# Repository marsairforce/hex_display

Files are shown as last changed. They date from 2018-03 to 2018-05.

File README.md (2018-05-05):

A 4 digit (16 bit) binary to 7-segment display.

Wanting to have some convenient module for displaying address bus contents.

# What is this and why would I want this?
If you were playing with an old retro computer type of architecture, on a breadboard, and you wanted to view the contents of like the address bus, or a data bus as a hexadecimal value.

In a simpler time when building microcontrollers using discrete CPU to simple static RAM and EEPROM devices. Back when the interconnects between teh CPU, ROM, RAM, and peripherals were the separate parallel busses, like simple 16 bit address bus, 8 bit data bus, the control bus, etc.

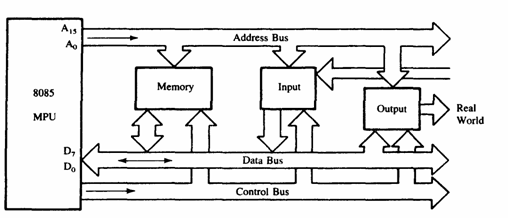
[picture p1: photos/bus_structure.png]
bus stucture


Now a days one would just spend $20 and get an Arduino, or $30 and get a Raspberry pi. and then connect it by USB to your laptop. And make use of the variety of widely avaialable community software. The hard work of design has been done for you.

But when working with these old parallel binary bus types of architectures, it is useful to be able to see what is going on when you are developing the hardware and the bare-metal software.

Usually you would be a monitor and debug panel with LED and switches on it. And then you have to look at the LEDs and interpret the value of these.

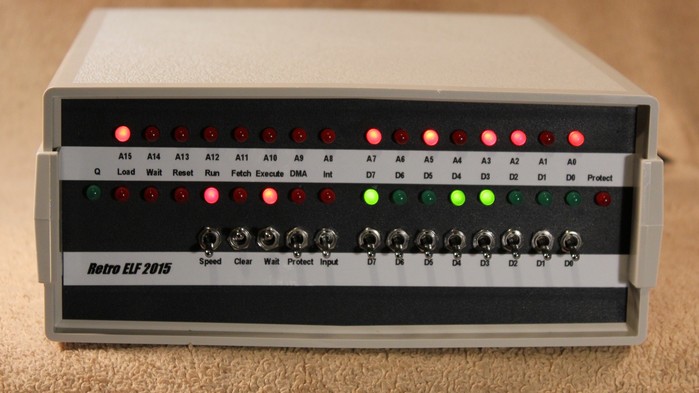
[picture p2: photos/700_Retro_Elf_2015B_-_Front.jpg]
led panel


Photo from [astrorat.com](http://www.astrorat.com/cosmacelf/retroelf2015.html)

But if you are used to thinking in base 16 instead of binary, then having a hexadecimal display is much better. Trying to fight the process and interpret the binary LEDS is very slow, tedious, and error prone.

Only usually if you have to want a binary-to-hex display, then you have wire up your own decoder, because there does not readily exist a binary-to-hex decoder IC.

Ok, so we can think about this and design a truth table for what pins to the LED display we want to have activated depending on what binary input there is.
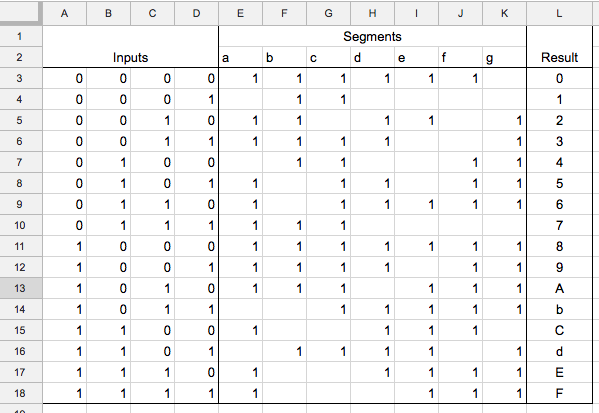
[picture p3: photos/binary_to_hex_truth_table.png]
truth table


You want to make four of these for your 16 bit address bus and another two for your 8 bit data bus. The discrete logic components required to do this take up as much if not more breadboard space as the rest of your microcontroller circuits. And the displays are horribly spaced randomly about your breadboard and you can hardly read them now too.

I guess sometimes it is possible where you might have access to a [GAL device](https://en.wikipedia.org/wiki/Generic_array_logic), but not as likely that you would have, or can afford, the programmer for these, because you are just an enthustiac hobbyist and trying to learn something new here and only have a pile of ~~rubbish~~ retro computer parts and a breadboard to play with. That would be awesome and elegant to craft a single inexpensive DIP device as your binary to Hex digit decoder though...

But then it is still tedious and error prone to have to wire up your testing tools when you are trying to use them to test things. Because every time you wire it up you have to go through the process of testing your testing tool.

What if you just had a convenient module you could just plug into a breadboard and have it readily display the decoded bus contents. That is what this does.

Inspired by https://www.youtube.com/watch?v=o9eQ9NhFT60

# V1 Hardware
This is a 28 DIP form factor circuit board using an Atmega 164A. Because it has a lot of IO pins.

Using Atmega164A device and 4 10mm 7 segment displays.

<table>
<tr><td>
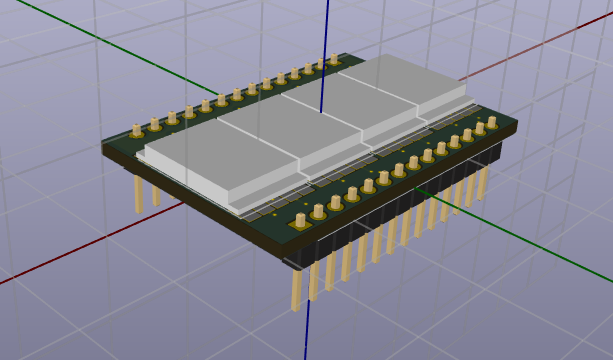
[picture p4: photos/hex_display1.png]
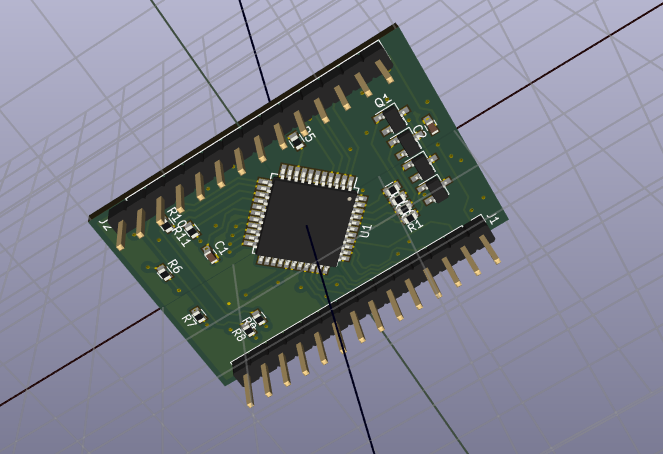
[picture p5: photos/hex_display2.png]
</td><td></td></tr></table>

The device was chosen because it has enough IO pins to directly drive all the segments with display multiplexing (the common anodes, using a transistor driver).

It was supposed to be a 28 pin dip format, but it is accidentally almost too wide to fit on a breadboard. Well, almost too wide. Some creative wiring under the display module on the breadboard should work.

Since we have pins for the MISO, MOSI, SCK. We can have a mode where this thing is an I2C or SPI slave and displays values on an I2C bus? That might be an intersting use. A display module. Though I would probably just use it as a clock since thats all I seem to build these days.

The schematic is set up to have the 16 address pins, an output enable pin and a latch enable pin.

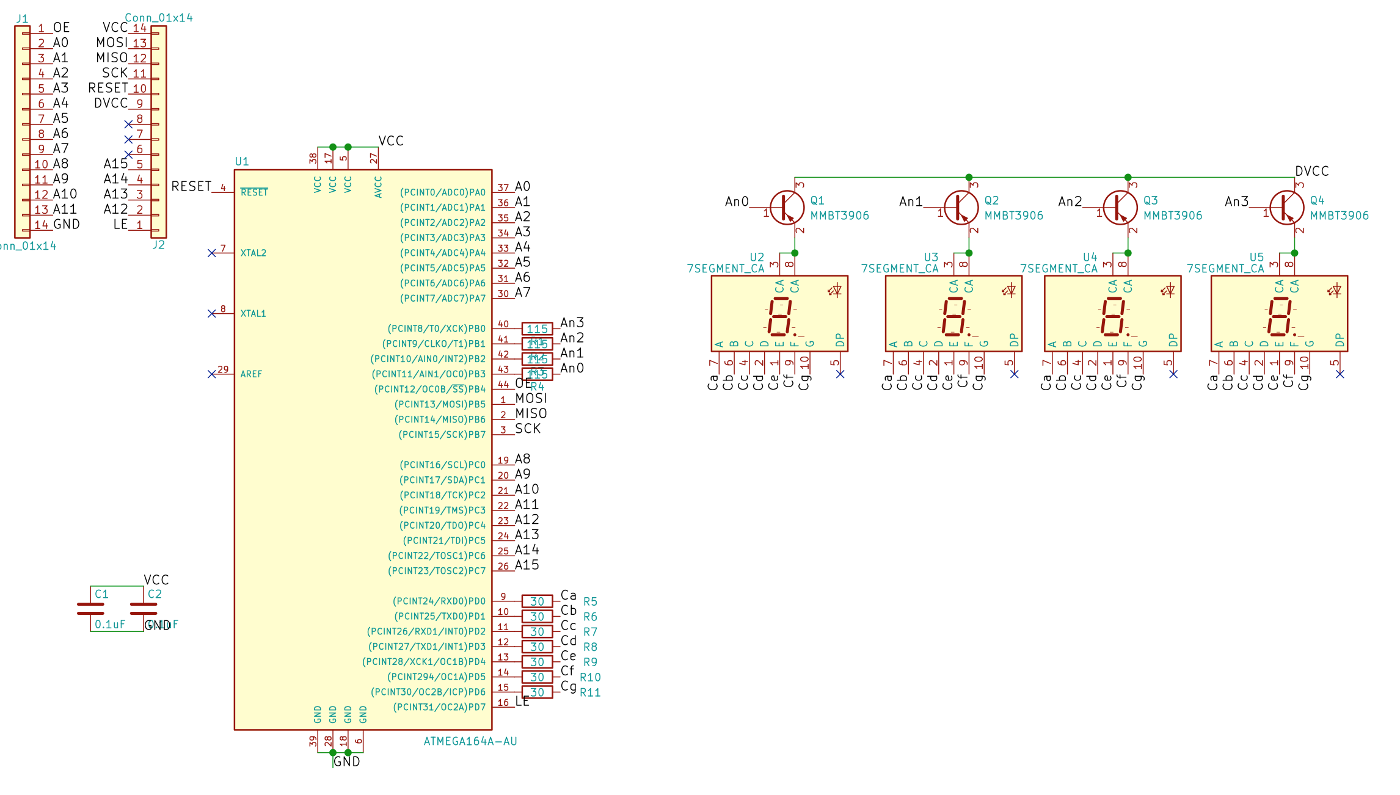
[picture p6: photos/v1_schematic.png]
v1 schematic


So the idea is to read the input pin values. and then display value as hex, using software to multiplex the displays.

And then here it is built and getting tested.
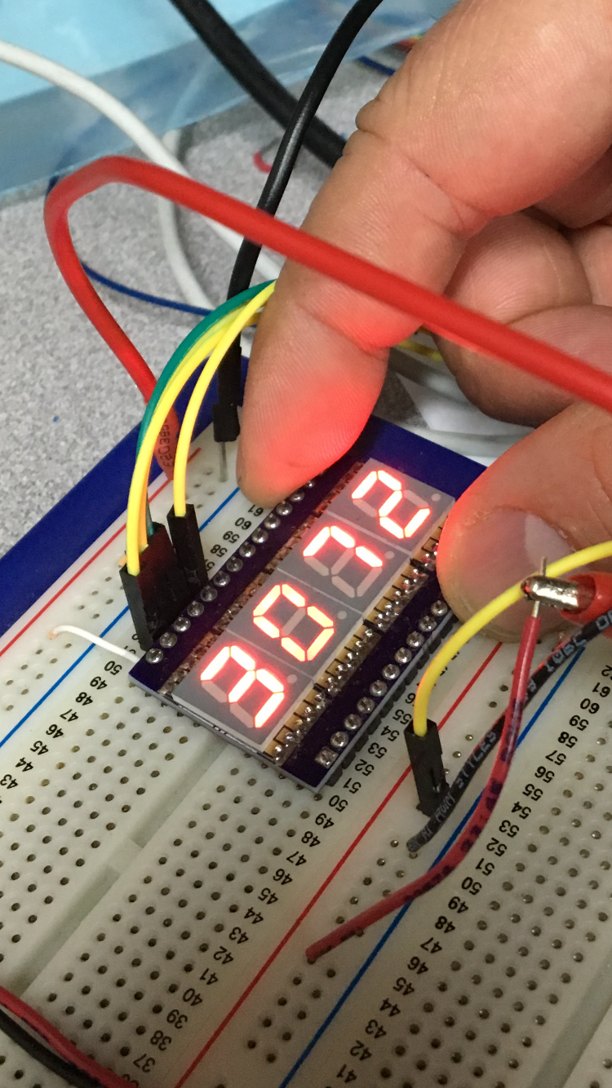
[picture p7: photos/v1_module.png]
v1 module


I made a small program to just loop and count up digits to test it, so I don't have to wire up input switches.

# Programming
At first I had some learning curve to program this. I was using the Arduino IDE (instead of spending time to get avr-gcc and the tool chain to work on its own with a Makefile, becuase.. macbook here..).

The AT164A is not directly supported hardware, but there is this project for [MightyCore](https://github.com/MCUdude/MightyCore) that seems to bring the AT164 support among others to the Arduino IDE.

I tried to use the "Arduino as ISP" sketch to create an ICSP and attached it to the pings on my module. Though it would not be recognized still.  I verified the Arduino as ISP setup worked by programming an Attiny85. That led to a tangent project to learn how to build a HVSP programmer on a second arduino to rese the fuzes, because I bricked the Attiny85 by accident. And then the desire to create an all in one programmer that can handle both cases. But that fell apart when I discovered there is already a usbtiny programmer project and not wanting to lose focus on the bigger picture which was to get this damn device I built in like February (it is now late April) to program so I can just see if it even works. You know. prototyping by designing and fabricating a PCB from the get go because stupid surface mount everything, what can possibly go wrong. Oh right, everything.

So then putting some energy into to build the usbtinyisp, as maybe that would work for me instead of the Arduino as ISP thing, but feeling no budget lately, and then remembering I had a bunch of Digispark devices that have the same-ish kind of hardware that the usbtiny programmer has. So then the idea to use this as a usbtiny isp. And a few iterations with the arduino as isp and HVSP programmers to realize the USB cable I was using for it was really a 2 wire power cable and not even a USB cable at all. How many sleepless nights are we up to now anyway. At least we now have a fork on Github for the [vusbtiny](https://github.com/marsairforce/vusbtiny) project, with digispark hardware.

So getting the usbtiny programmer to work, and then learning we need to edit the avrdude.conf file to allow it to recognize the Atmega164A device. And then learning the Arduino IDE supports a `Upload using programmer` mode, so then going back to just using that. And here we are. Other than some random crazy ramblings and a somewhat arbitrary path to get here, I have uninteligently managed to use Arduino IDE with MightyCore, the updated avrdude.conf, with a usbtinyisp.

# TODO
Some ideas so far for improment:

* Lay out the board to be not as tall. It barely fits on a breadboard now. Maybe need to use slightly smaller displays. The priority at the time was to have the edges flat and narrow so two or modules could be placed side by side for a 32 bit readout. But then we forgot we can't be too tall either.

* Create a socket adapter module to fit a standard 27xx series (E)EPROM type of DIP socket, with the pin outs of these memory devices. So we can have the hex display show the contents of the address bus. The use case here is we could place this display into a socket on a motherboard of an existing retro computer, or piggy back it onto the (E)EPROM so we can see what is going on when the computer is operating.

* Design an 8 bit version. So we can see 8 bit bus things as well. Just 2 digits then.  Maybe we can use a smaller microcontroller then, like just the At328p.

* Improve the firmware. Investigate using C and avr-gcc directly. Learning more about the registers and internal details of the microcontroller. For now the delays in the visual display of numbers were thought to be "good enough". Using the internal uncalibrated oscillator of the device, so nothing timing critical going on here too.

* Investigate adding serial input option, i2c slave feature (using the USIwire, because the SDA/SCL pins for hardware TWI are also PC0..PC1, which is A8 and A9 inputs) or SPI. We have the SPI pins on PB5..PB7 for programming, but not used in normal operation.

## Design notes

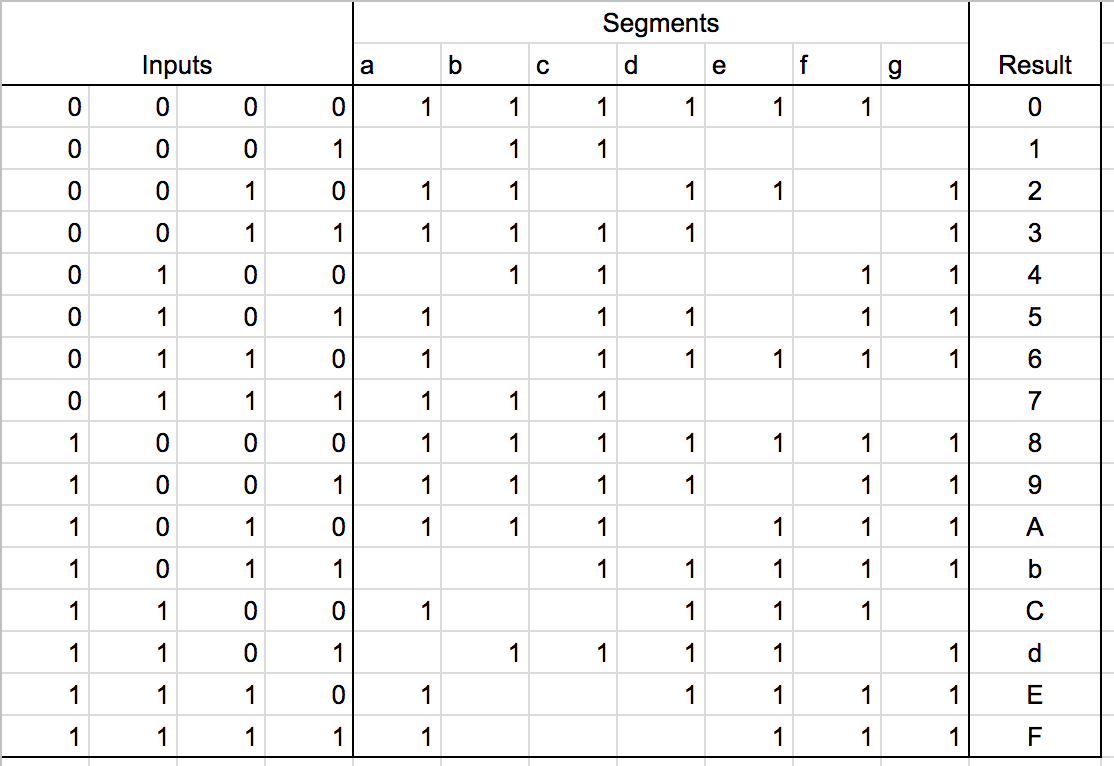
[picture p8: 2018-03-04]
photos/Screen Shot 2018-03-03 at 10.00.10 PM.png

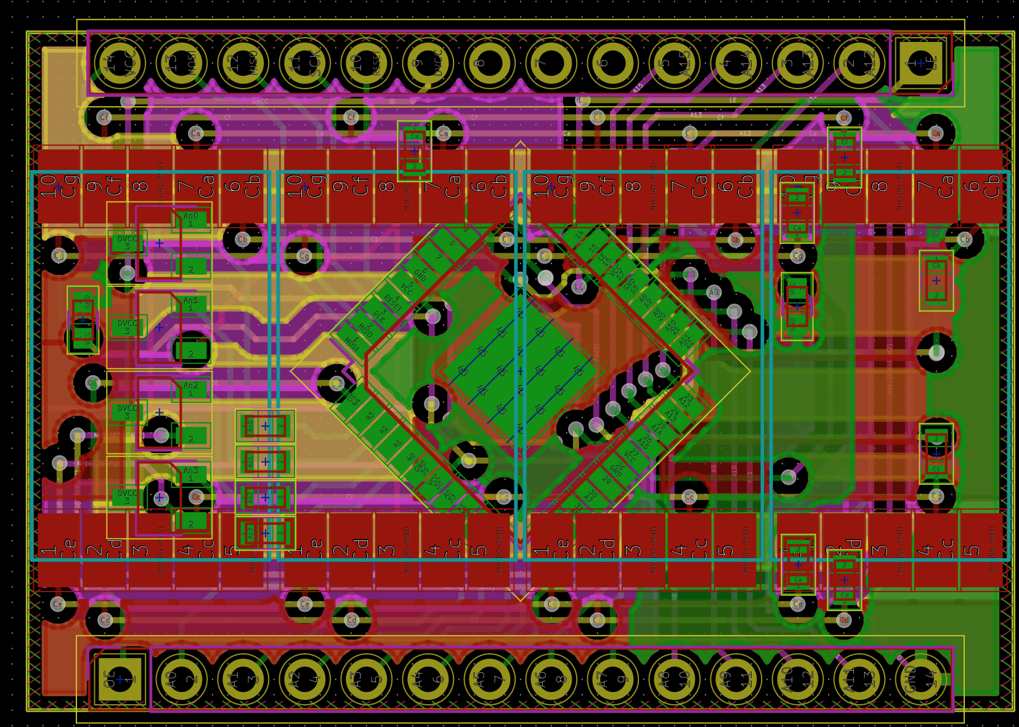
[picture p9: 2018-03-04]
photos/Screen Shot 2018-03-03 at 10.37.07 PM.png

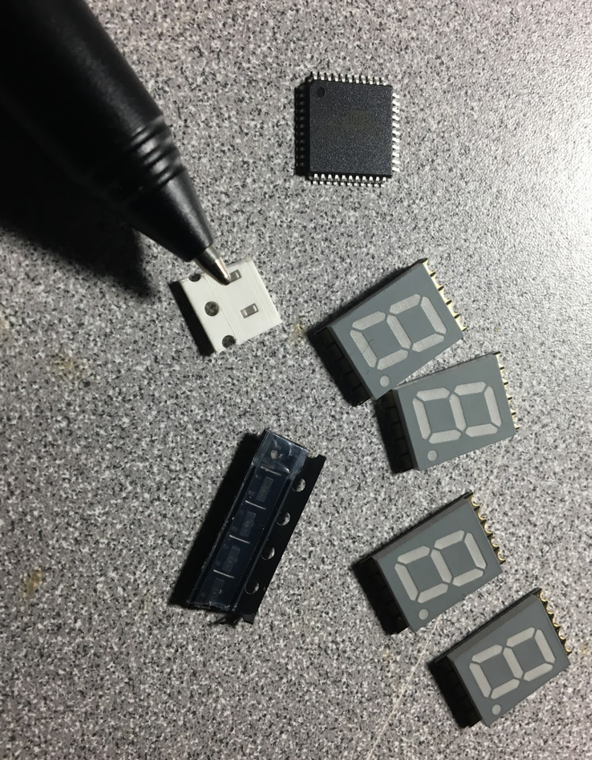
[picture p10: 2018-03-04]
photos/Screen Shot 2018-03-03 at 10.24.54 PM.png

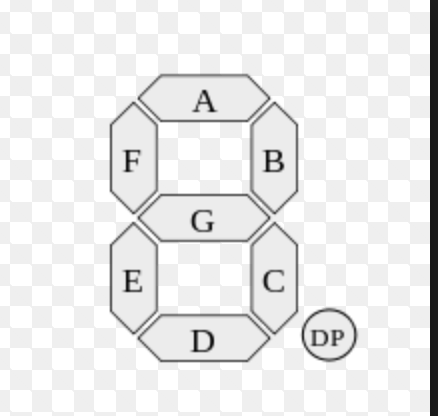
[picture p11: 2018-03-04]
photos/Screen Shot 2018-03-03 at 9.55.36 PM.png

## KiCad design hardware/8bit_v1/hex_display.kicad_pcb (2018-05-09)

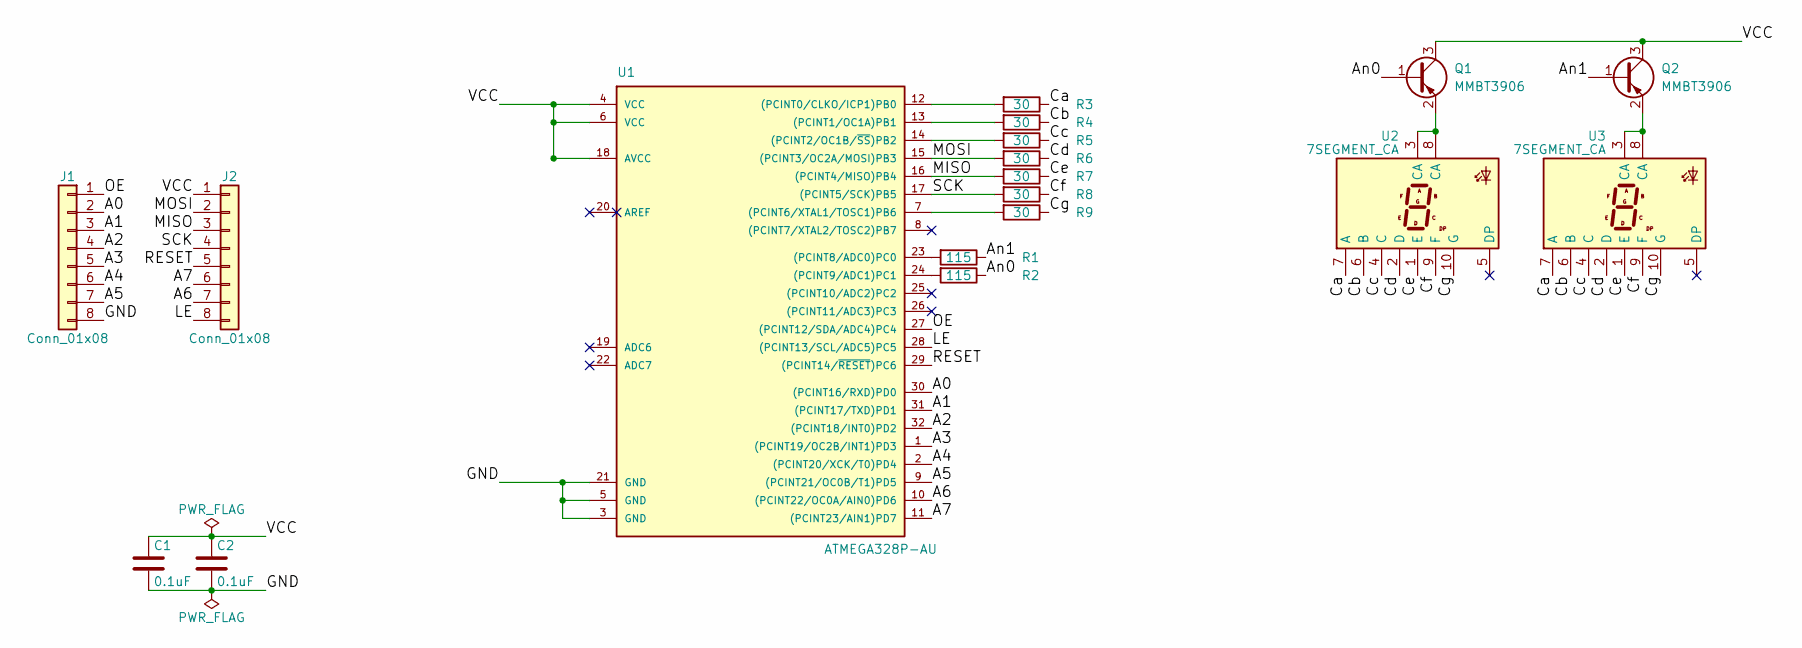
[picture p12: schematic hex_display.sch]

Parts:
C1, C2: 0.1uF; C_0603
J1, J2: Conn_01x08; Pin_Header_Straight_1x08_Pitch2.54mm
Q1, Q2: MMBT3906; TSOT-23
R1, R2: 115; R_0603
R3, R4, R5, R6, R7, R8, R9: 30; R_0603
U1: ATMEGA328P-AU; TQFP-32_7x7mm_Pitch0.8mm
U2, U3: 7SEGMENT_CA; VDMR10A1

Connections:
/A0: J1.2, U1.30 ((PCINT16/RXD)PD0)
/A1: J1.3, U1.31 ((PCINT17/TXD)PD1)
/A2: J1.4, U1.32 ((PCINT18/INT0)PD2)
/A3: J1.5, U1.1 ((PCINT19/OC2B/INT1)PD3)
/A4: J1.6, U1.2 ((PCINT20/XCK/T0)PD4)
/A5: J1.7, U1.9 ((PCINT21/OC0B/T1)PD5)
/A6: J2.7, U1.10 ((PCINT22/OC0A/AIN0)PD6)
/A7: J2.6, U1.11 ((PCINT23/AIN1)PD7)
/An0: Q1.1 (B), R2.1
/An1: Q2.1 (B), R1.1
/Ca: R3.1, U2.7 (A), U3.7 (A)
/Cb: R4.1, U2.6 (B), U3.6 (B)
/Cc: R5.1, U2.4 (C), U3.4 (C)
/Cd: R6.1, U2.2 (D), U3.2 (D)
/Ce: R7.1, U2.1 (E), U3.1 (E)
/Cf: R8.1, U2.9 (F), U3.9 (F)
/Cg: R9.1, U2.10 (G), U3.10 (G)
/GND: C1.2, C2.2, J1.8, U1.3 (GND), U1.5 (GND), U1.21 (GND)
/LE: J2.8, U1.28 ((PCINT13/SCL/ADC5)PC5)
/MISO: J2.3, R7.2, U1.16 ((PCINT4/MISO)PB4)
/MOSI: J2.2, R6.2, U1.15 ((PCINT3/OC2A/MOSI)PB3)
/OE: J1.1, U1.27 ((PCINT12/SDA/ADC4)PC4)
/RESET: J2.5, U1.29 ((PCINT14/~RESET~)PC6)
/SCK: J2.4, R8.2, U1.17 ((PCINT5/SCK)PB5)
/VCC: C1.1, C2.1, J2.1, Q1.3 (C), Q2.3 (C), U1.4 (VCC), U1.6 (VCC), U1.18 (AVCC)
unnamed: Q1.2 (E), U2.3 (CA), U2.8 (CA)
unnamed: Q2.2 (E), U3.3 (CA), U3.8 (CA)
unnamed: R1.2, U1.23 ((PCINT8/ADC0)PC0)
unnamed: R2.2, U1.24 ((PCINT9/ADC1)PC1)
unnamed: R3.2, U1.12 ((PCINT0/CLKO/ICP1)PB0)
unnamed: R4.2, U1.13 ((PCINT1/OC1A)PB1)
unnamed: R5.2, U1.14 ((PCINT2/OC1B/~SS~)PB2)
unnamed: R9.2, U1.7 ((PCINT6/XTAL1/TOSC1)PB6)

Board: 4 copper layers, 18 parts (0 on the bottom side), 33 nets, no tracks yet.

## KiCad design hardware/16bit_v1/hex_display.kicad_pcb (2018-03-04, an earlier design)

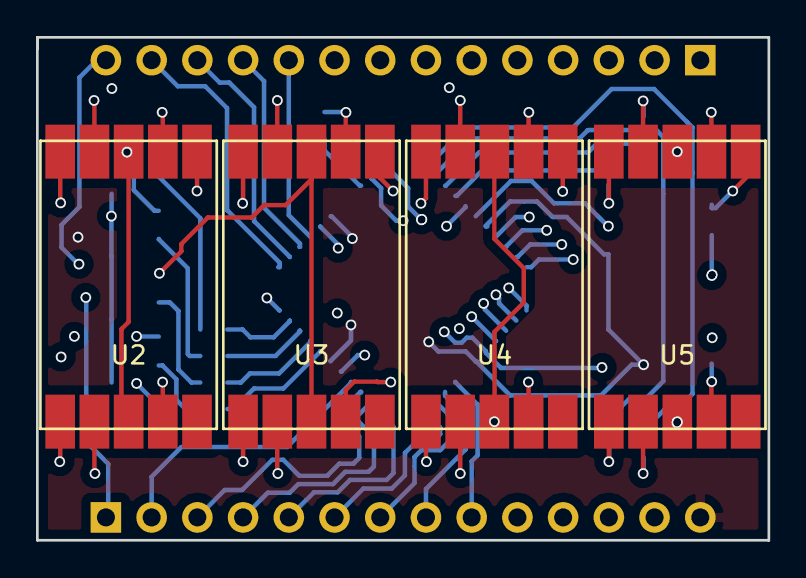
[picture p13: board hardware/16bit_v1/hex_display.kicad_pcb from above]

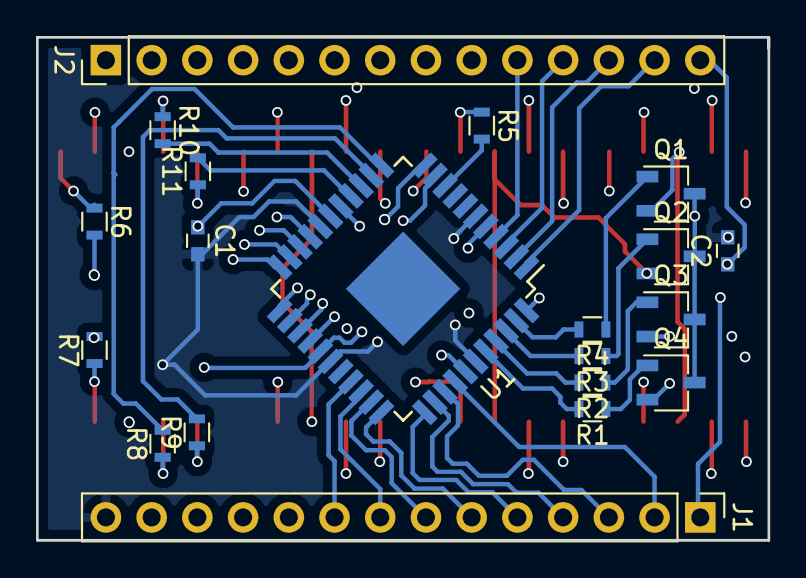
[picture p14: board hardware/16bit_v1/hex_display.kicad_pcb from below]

Board: 4 copper layers, 40.6 x 27.9 mm, 24 parts (20 on the bottom side), 51 nets.

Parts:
C1, C2: 0.1uF; C_0603
J1, J2: Conn_01x14; Pin_Header_Straight_1x14_Pitch2.54mm
Q1, Q2, Q3, Q4: MMBT3906; TSOT-23
R1, R2, R3, R4: 300; R_0603
R5, R6, R7, R8, R9, R10, R11: 115; R_0603
U1: ATMEGA164A-AU; TQFP-44-1EP_10x10mm_Pitch0.8mm
U2, U3, U4, U5: 7SEGMENT_CA; VDMR10A1

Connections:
/A0: J1.2, U1.37
/A1: J1.3, U1.36
/A2: J1.4, U1.35
/A3: J1.5, U1.34
/A4: J1.6, U1.33
/A5: J1.7, U1.32
/A6: J1.8, U1.31
/A7: J1.9, U1.30
/A8: J1.10, U1.19
/A9: J1.11, U1.20
/A10: J1.12, U1.21
/A11: J1.13, U1.22
/A12: J2.2, U1.23
/A13: J2.3, U1.24
/A14: J2.4, U1.25
/A15: J2.5, U1.26
/An0: Q1.1, R4.1
/An1: Q2.1, R3.1
/An2: Q3.1, R2.1
/An3: Q4.1, R1.1
/Ca: R5.1, U2.7, U3.7, U4.7, U5.7
/Cb: R6.1, U2.6, U3.6, U4.6, U5.6
/Cc: R7.1, U2.4, U3.4, U4.4, U5.4
/Cd: R8.1, U2.2, U3.2, U4.2, U5.2
/Ce: R9.1, U2.1, U3.1, U4.1, U5.1
/Cf: R10.1, U2.9, U3.9, U4.9, U5.9
/Cg: R11.1, U2.10, U3.10, U4.10, U5.10
/DVCC: J2.9, Q1.3, Q2.3, Q3.3, Q4.3
/GND: C1.2, C2.2, J1.14, U1.6, U1.18, U1.28, U1.39
/LE: J2.1, U1.16
/MISO: J2.12, U1.2
/MOSI: J2.13, U1.1
/OE: J1.1, U1.44
/RESET: J2.10, U1.4
/SCK: J2.11, U1.3
/VCC: C1.1, C2.1, J2.14, U1.5, U1.17, U1.27, U1.38
unnamed: Q1.2, U2.3, U2.8
unnamed: Q2.2, U3.3, U3.8
unnamed: Q3.2, U4.3, U4.8
unnamed: Q4.2, U5.3, U5.8
unnamed: R1.2, U1.40
unnamed: R2.2, U1.41
unnamed: R3.2, U1.42
unnamed: R4.2, U1.43
unnamed: R5.2, U1.9
unnamed: R6.2, U1.10
unnamed: R7.2, U1.11
unnamed: R8.2, U1.12
unnamed: R9.2, U1.13
unnamed: R10.2, U1.14
unnamed: R11.2, U1.15

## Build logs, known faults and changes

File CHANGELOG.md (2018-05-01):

# Revisions

## 1.0
* Hardware design using At164A microcontroller, surface mount 7 segment displays on a PCB.
* Software done using Arduino IDE and MightyCore configuration for AVR devices.

## 0.1
Was thinking VDMR10A1CT-ND, since 10mm display height.
A 16 bit module has 4 digits. An 8 bit module can use the same logic, just having less inputs and 2 displays.

Really we could use a micro controller to read latched inputs into shift registers. serially read them in and then use display multiplexing to write out the display values. This could have support for external latching(LE), display blanking (OE).

The best fitting controller seems to be the Atmega 164 ATMEGA164A-AURCT-ND. 32 io lines. 20mHz. (16 for input, 7 for segment cathodes, 4 for segment anodes, 1 for OE, 1 for LE, 2 for for selecting mode (continuous, latch single, latch multiple, read out), 1 for reset. We can have it store several values  read on input into internal arrays as it reads them in, so we could later halt the CPU and review the sequences that were observed.

So this makes the components just the 7 segment displays, micro controller, resistors, power filtering capacitors).

Aim to package it into a wide 24 pin DIP footprint.  (18.53mm wide x 30.9mm long)

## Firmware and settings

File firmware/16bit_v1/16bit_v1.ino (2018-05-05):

/**
 * Using an Atmega 164A as a binary to hex display driver.
 * Soldered onto the circuit board with the LED digits.
 * And the need to map the IC pins to an arduino "pin" number
 * I used https://camo.githubusercontent.com/46718caeab6022a330ffed7f27109c147a16ba56/68747470733a2f2f692e696d6775722e636f6d2f735954747555492e6a7067
 * Inputs:
 * | Function | IC | Atmega | Pin | Aruino Pin reference
 * |      /OE |  1 |    PB4 |  44 |    4 |
 * |       A0 |  2 |    PA0 |  37 |   24 |
 * |       A1 |  3 |    PA1 |  36 |   25 |
 * |       A2 |  4 |    PA2 |  35 |   26 |
 * |       A3 |  5 |    PA3 |  34 |   27 |
 * |       A4 |  6 |    PA4 |  33 |   28 |
 * |       A5 |  7 |    PA5 |  32 |   29 |
 * |       A6 |  8 |    PA6 |  31 |   30 |
 * |       A7 |  9 |    PA7 |  30 |   31 |
 * |       A8 | 10 |    PC0 |  19 |   16 |
 * |       A9 | 11 |    PC1 |  20 |   17 |
 * |      A10 | 12 |    PC2 |  21 |   18 |
 * |      A11 | 13 |    PC3 |  22 |   19 |
 * |      A12 | 16 |    PC4 |  23 |   20 |
 * |      A13 | 17 |    PC5 |  24 |   21 |
 * |      A14 | 18 |    PC6 |  25 |   22 |
 * |      A15 | 19 |    PC7 |  26 |   23 |
 * |       LE | 15 |    PD7 |  16 |   15 |
 * |       NC | 20 |        |     |      |
 * |       NC | 21 |        |     |      |
 * |       NC | 22 |        |     |      |
 * |     DVCC | 23 |        |     |      |
 * |    RESET | 24 |  RESET |   4 |      |
 * |      SCK | 25 |    SCK |   3 |    7 |
 * |     MISO | 26 |   MISO |   2 |    6 |
 * |     MOSI | 27 |   MOSI |   1 |    5 |
 * |      GND | 14 |    GND | 6,18,28,39 |
 * |      VCC | 28 |    VCC | 5,17,27,38 |
 *
 *
 * Connections to LEDs:
 * | Function | Atmega | Pin | Arduino Pin Reference |
 * |       Ca |    PD0 |   9 |   8 |
 * |       Cb |    PD1 |  10 |   9 |
 * |       Cc |    PD2 |  11 |  10 |
 * |       Cd |    PD3 |  12 |  11 |
 * |       Ce |    PD4 |  13 |  12 |
 * |       Cf |    PD5 |  14 |  13 |
 * |       Cg |    PD6 |  15 |  14 |
 * |
 * |      An0 |    PB3 |  43 |   3 |
 * |      An1 |    PB2 |  42 |   2 |
 * |      An2 |    PB1 |  41 |   1 |
 * |      An3 |    PB0 |  40 |   0 |

 * Not connected: 
 * |          |  XTAL2 |   7 |
 * |          |  XTAL1 |   8 |
 * |          |   AREF |  29 |
 * 
 * Programming: 
 * Use an Arduino UNO, loaded with the "Arduino ISP sketch"
 * Then wire up as
 * | Function | Arduino | ICSP | DISPLAY | 164A |
 * |      VCC |      5V |    2 |      28 |    5 |
 * |     MOSI |      11 |    4 |      27 |    1 |
 * |     MISO |      12 |    1 |      26 |    2 |
 * |      SCK |      13 |    3 |      25 |    3 |
 * |    RESET |      10 |    5 |      24 |    4 |
 * |      GND |     GND |    6 |      14 |    6 |
 * 
 
 */

#define PIN_AN0   3
#define PIN_AN1   2
#define PIN_AN2   1
#define PIN_AN3   0

#define PIN_MOSI  5
#define PIN_MISO  6
#define  PIN_SCK   7

#define PIN_CA    8
#define PIN_CB    9
#define PIN_CC    10
#define PIN_CD    11
#define PIN_CE    12 
#define PIN_CF    13
#define PIN_CG    14

#define PIN_LE    15
#define PIN_OE    4

#define PIN_A0    24
#define PIN_A1    25
#define PIN_A2    26
#define PIN_A3    27
#define PIN_A4    28
#define PIN_A5    29
#define PIN_A6    30
#define PIN_A7    31
#define PIN_A8    16
#define PIN_A9    17
#define PIN_A10   18
#define PIN_A11   19
#define PIN_A12   20
#define PIN_A13   21
#define PIN_A14   22
#define PIN_A15   23


// bit matrix for active low cathodes to display 0..F
// where this is really just port D, segment a is LSB, segment g is bit 0x40 (mask is 0x7F)
// 0  100 0000    0x40
// 1  111 1001    0x79
// 2  010 0100    0x24
// 3  011 0000    0x30
// 4  001 1001    0x19
// 5  001 0010    0x12
// 6  000 0010    0x02
// 7  111 1000    0x78
// 8  000 0000    0x00
// 9  001 1000    0x18
// A  000 1000    0x08
// b  000 0011    0x03
// C  100 0110    0x46
// d  010 0001    0x21
// E  000 0110    0x06
// F  000 1110    0x0E

const char digits[16] = { 0x40, 0x79, 0x24, 0x30, 0x19, 0x12, 0x02, 0x78, 0x00, 0x18, 0x08, 0x03, 0x46, 0x21, 0x06, 0x0E };

void setup() {
  pinMode(PIN_AN0, OUTPUT);
  pinMode(PIN_AN1, OUTPUT);
  pinMode(PIN_AN2, OUTPUT);
  pinMode(PIN_AN3, OUTPUT);
  
  pinMode(PIN_CA, OUTPUT);
  pinMode(PIN_CB, OUTPUT);
  pinMode(PIN_CC, OUTPUT);
  pinMode(PIN_CD, OUTPUT);
  pinMode(PIN_CE, OUTPUT);
  pinMode(PIN_CF, OUTPUT);
  pinMode(PIN_CG, OUTPUT);

  pinMode(PIN_LE, INPUT_PULLUP);
  pinMode(PIN_OE, INPUT_PULLUP);

  pinMode(PIN_A0, INPUT_PULLUP);
  pinMode(PIN_A1, INPUT_PULLUP);
  pinMode(PIN_A2, INPUT_PULLUP);
  pinMode(PIN_A3, INPUT_PULLUP);
  pinMode(PIN_A4, INPUT_PULLUP);
  pinMode(PIN_A5, INPUT_PULLUP);
  pinMode(PIN_A6, INPUT_PULLUP);
  pinMode(PIN_A7, INPUT_PULLUP);
  pinMode(PIN_A8, INPUT_PULLUP);
  pinMode(PIN_A9, INPUT_PULLUP);
  pinMode(PIN_A10, INPUT_PULLUP);
  pinMode(PIN_A11, INPUT_PULLUP);
  pinMode(PIN_A12, INPUT_PULLUP);
  pinMode(PIN_A13, INPUT_PULLUP);
  pinMode(PIN_A14, INPUT_PULLUP);
  pinMode(PIN_A15, INPUT_PULLUP);

  // initially all cathodes and anodes off
  digitalWrite(PIN_CA, HIGH);
  digitalWrite(PIN_CB, HIGH);
  digitalWrite(PIN_CC, HIGH);
  digitalWrite(PIN_CD, HIGH);
  digitalWrite(PIN_CE, HIGH);
  digitalWrite(PIN_CF, HIGH);
  digitalWrite(PIN_CG, HIGH);

  digitalWrite(PIN_AN0, HIGH);
  digitalWrite(PIN_AN1, HIGH);
  digitalWrite(PIN_AN2, HIGH);
  digitalWrite(PIN_AN3, HIGH);

}

// storage for what we read from [A0..A15] inputs

int raw_value = 0;
int s = 1;
// port C is MSB, port A is LSB
void read_raw_value() {
    raw_value = (PINC << 8) | PINA;
}

void display_value() {
  PORTB &= ~0x0F;
  PORTB |= 0x07;  
  PORTD &= ~0x7F; // clear all digit bits
  PORTD |= digits[(raw_value & 0xF000) >> 12];
  delay(s);

  PORTB &= ~0x0F;
  PORTB |= 0x0B;
  PORTD &= ~0x7F; // clear all digit bits
  PORTD |= digits[(raw_value & 0x0F00) >> 8];
  delay(s);

  PORTB &= ~0x0F;
  PORTB |= 0x0D;
  PORTD &= ~0x7F; // clear all digit bits
  PORTD |= digits[(raw_value & 0x00F0) >> 4];
  delay(s);

  PORTB &= ~0x0F;
  PORTB |= 0x0E;
  PORTD &= ~0x7F; // clear all digit bits
  PORTD |= digits[(raw_value & 0x000F) ];
  delay(s );

  PORTB &= ~0x0F;
  PORTB |= 0x0F;
}

int counter = 0;
void loop() {
//  raw_value = 0x8888;
  if (PIND & 0x80) { // only read inputs if LE is not 0.
    read_raw_value();
  } 

  // only display things if OE is low
  if ((PINB & 0x10)) {
    display_value();
  }
//  if (counter % 200 == 0) {
//    raw_value ++;
//    counter = 0;
//  }
}

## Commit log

2018-03-04 v1 design
    board layout shipped to oshpark for processing
    https://oshpark.com/orders/PoUPhUu6
    [hex_display.kicad_pcb, hex_display.sch]
2018-03-24 assemble the board. change drive resistor to transistor. start a sketch to test the device. having problems being able to program it. not sure if this is the device, or the arduino or the macbook.
    [hex_display.sch]
2018-05-01 change out resistor values
    during testing, noticed the displays seemed kind of dim. Experimented with values I had handy until it looked good.
    [hex_display.sch]
2018-05-09 move kicad files to hardware 16bit_v1 folder move firmware file to 16bit_v1 folder
    [hex_display.kicad_pcb, hex_display.sch]
2018-05-09 start an 8 bit design.
    took an attempt to lay out a PCB design. but it was a bloody mess so i deleted it out of anger because i wasted several hours trying to make it work.
    [hex_display.kicad_pcb, hex_display.sch]
